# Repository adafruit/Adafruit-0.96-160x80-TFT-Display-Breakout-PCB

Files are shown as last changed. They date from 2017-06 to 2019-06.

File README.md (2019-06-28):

## Adafruit 0.96" 160x80 TFT LCD Display Breakout PCB

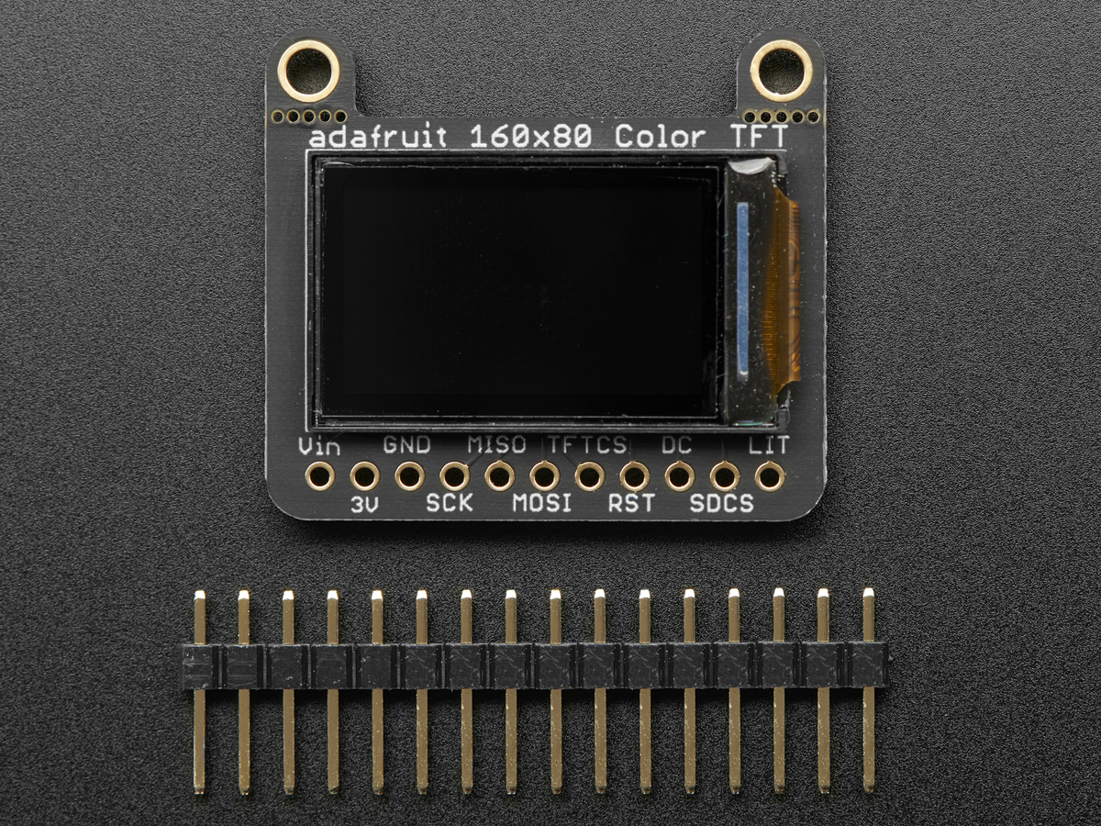
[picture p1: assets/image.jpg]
<a href="http://www.adafruit.com/products/3533"><br/>
Click here to purchase one from the Adafruit shop</a>

PCB files for the Adafruit 0.96" 160x80 TFT Display Breakout. Format is EagleCAD schematic and board layout

For more details, check out the product pages at
* https://www.adafruit.com/products/3533

### Description

Say hello to our 0.96" 160x80 Color TFT Display w/ MicroSD Card Breakout – we think it's T-F-Terrific! It's the size of your thumbnail, with glorious 160x80 pixel color. This very very small display is only 0.96" diagonal, packed with RGB pixels, for making very small high-density displays.

This lovely little display breakout is a great way to add a small, colorful and bright display to any project. Since the display uses 4-wire SPI to communicate and has its own pixel-addressable frame buffer, it can be used with every kind of microcontroller. Even a very small one with low memory and few pins available!

The 0.96" display has 160x80 color pixels. Unlike the low cost "Nokia 6110" and similar LCD displays, which are CSTN type and thus have poor color and slow refresh, this display is a true TFT! The TFT driver (ST7735R) can display full 16-bit color using our library code.

The breakout has the TFT display soldered on (it uses a delicate flex-circuit connector) as well as a ultra-low-dropout 3.3V regulator and a 3/5V level shifter so you can use it with 3.3V or 5V power and logic. We also had a little space so we placed a microSD card holder so you can easily load full color bitmaps from a FAT16/FAT32 formatted microSD card. **The microSD card is not included.**

### License

Adafruit invests time and resources providing this open source design, please support Adafruit and open-source hardware by purchasing products from [Adafruit](https://www.adafruit.com)!

Designed by Limor Fried/Ladyada for Adafruit Industries.

Creative Commons Attribution/Share-Alike, all text above must be included in any redistribution. See license.txt for additional details.

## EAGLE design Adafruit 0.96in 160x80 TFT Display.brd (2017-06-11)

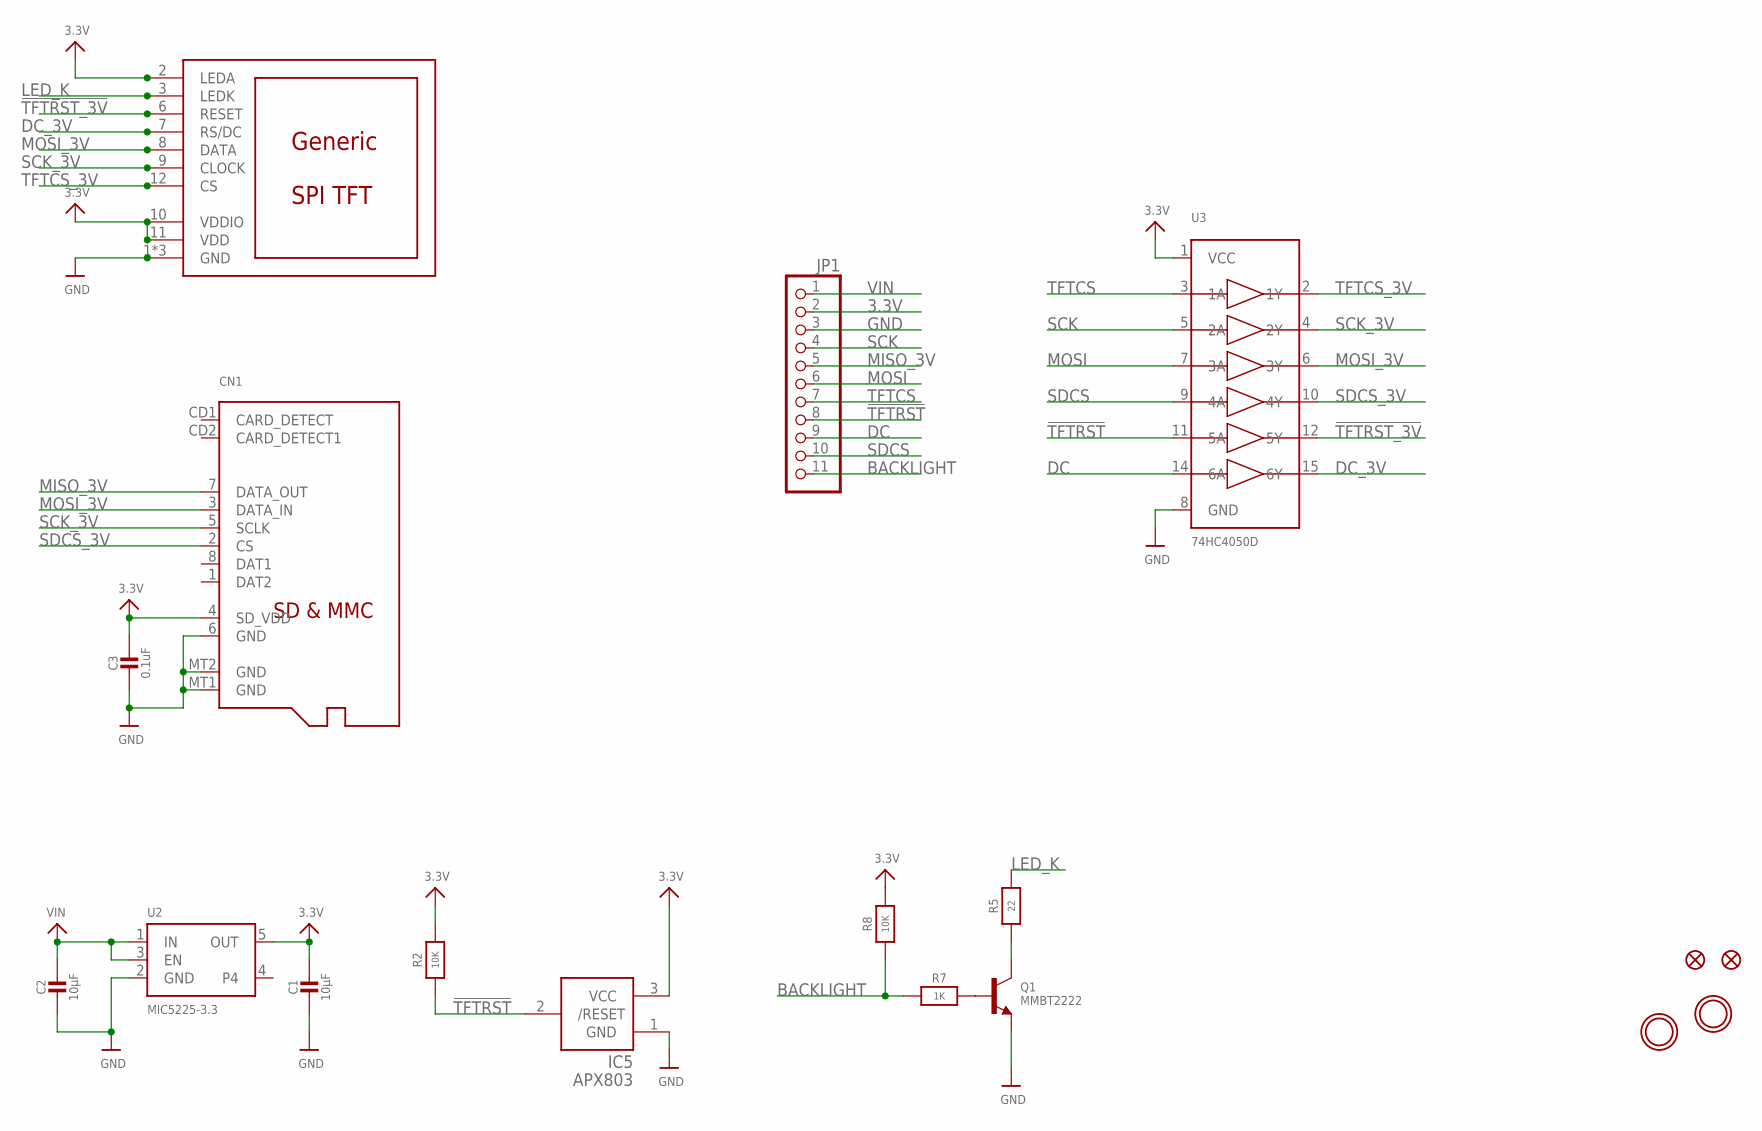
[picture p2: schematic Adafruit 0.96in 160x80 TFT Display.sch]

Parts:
C1, C2: 10µF; 0805-NO
C3: 0.1uF; 0805-NO
CN1: MICROSD
FID1, FID2: FIDUCIAL_1MM
IC5: APX803; SOT23
JP1: HEADER-1X11; 1X11_ROUND
Q1: MMBT2222; SOT23-WIDE
R2, R8: 10K; 0603-NO
R5: 22; 0603-NO
R7: 1K; 0603-NO
U2: MIC5225-3.3; SOT23-5
U3: 74HC4050D; SOIC16
U$2: DISP_LCD_0.9IN_160X80; TFT_0.96IN_160X80
U$9, U$10: MOUNTINGHOLE2.5; MOUNTINGHOLE_2.5_PLATED

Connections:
3.3V: C1.1, C3.1, CN1.4 (SD_VDD), IC5.3 (VCC), JP1.2, R2.2, R8.2, U2.5 (OUT), U3.1 (VCC), U$2.2 (LEDA), U$2.10 (VDDIO), U$2.11 (VDD)
!TFTRST: IC5.2 (/RESET), JP1.8, R2.1, U3.11 (5A)
!TFTRST_3V: U3.12 (5Y), U$2.6 (RESET)
BACKLIGHT: JP1.11, R7.1, R8.1
DC: JP1.9, U3.14 (6A)
DC_3V: U3.15 (6Y), U$2.7 (RS/DC)
GND: C1.2, C2.2, C3.2, CN1.6 (GND), CN1.MT1 (GND), CN1.MT2 (GND), IC5.1 (GND), JP1.3, Q1.2 (E), U2.2 (GND), U3.8 (GND), U$2.1 (GND), U$2.5 (GND), U$2.13 (GND)
LED_K: R5.2, U$2.3 (LEDK)
MISO_3V: CN1.7 (DATA_OUT), JP1.5
MOSI: JP1.6, U3.7 (3A)
MOSI_3V: CN1.3 (DATA_IN), U3.6 (3Y), U$2.8 (DATA)
unnamed: Q1.1 (B), R7.2
unnamed: Q1.3 (C), R5.1
SCK: JP1.4, U3.5 (2A)
SCK_3V: CN1.5 (SCLK), U3.4 (2Y), U$2.9 (CLOCK)
SDCS: JP1.10, U3.9 (4A)
SDCS_3V: CN1.2 (CS), U3.10 (4Y)
TFTCS: JP1.7, U3.3 (1A)
TFTCS_3V: U3.2 (1Y), U$2.12 (CS)
VIN: C2.1, JP1.1, U2.1 (IN), U2.3 (EN)

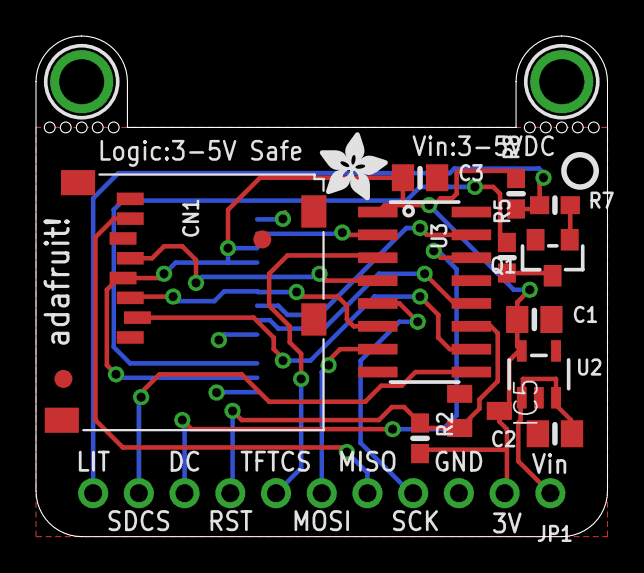
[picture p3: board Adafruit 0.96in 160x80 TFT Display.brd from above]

Board: 2 copper layers, 31.8 x 27.8 mm, 20 parts (1 on the bottom side), 20 nets.

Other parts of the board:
U$4: MICROSD; ADAFRUIT_3.5MM
U$6: PCBFEAT-REV-040
